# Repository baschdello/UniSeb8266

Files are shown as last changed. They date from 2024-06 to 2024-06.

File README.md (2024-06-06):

# UniSeb8266
Universal Sensorboard with ESP8266.

## Usage
### Tasmota
UniSeb8266 is designed to operate with Tasmota. Use the following template string:
```
{"NAME":"UniSeb8266","GPIO":[640,0,608,0,352,1312,0,0,0,1760,1,1728,1,0],"FLAG":0,"BASE":18}
```
### Power sources
There are different options to power the board:
| power source | SJ1 jumper position |
| --- | --- |
| HLK-PM01 230V-Module | 'module' |
| RT9400 PoE-Module | 'module' |
| 5V connector | 'connector' |
| D1-Mini USB connector  | no jumper required  |

### 3-pin connector J1
Use SJ2 to change usage of pin2:
| pin 2 utilization | SJ2 jumper position |
| --- | --- |
| 3.3V | '3V3' |
| gpio D5 | 'D5' |

Pin3 is fixed to D0.

## Examples
PM sensor mounted on diy box
<br>



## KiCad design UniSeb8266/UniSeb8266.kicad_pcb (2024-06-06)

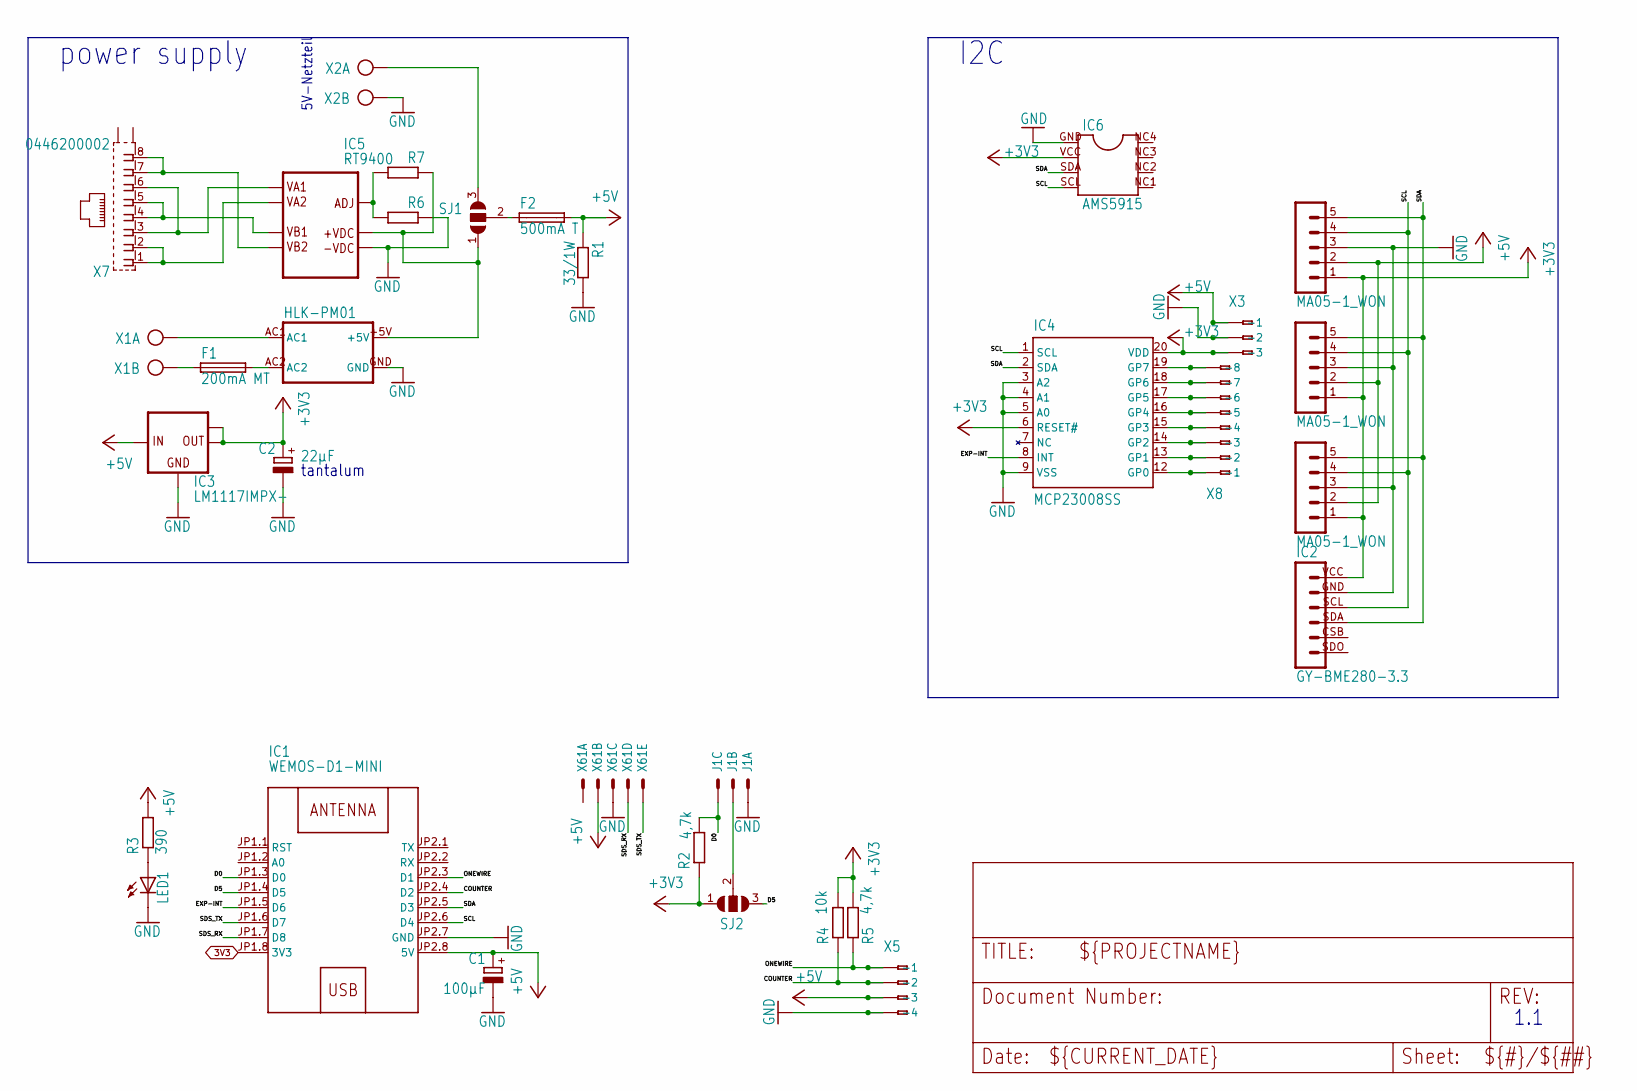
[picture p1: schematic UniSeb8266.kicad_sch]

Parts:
C1: 100µF; E2,5-6
C2: 22µF; E2,5-6
F1: 200mA MT; TR5
F2: 500mA T; TR5
I2C-1, I2C-2, I2C-3: MA05-1_WON
IC1: WEMOS-D1-MINI
IC2: GY-BME280-3.3
IC3: LM1117IMPX-; SOT223
IC4: MCP23008SS; SSOP20
IC5: RT9400
IC6: AMS5915
J1: 22-?-0327-2031; 6410-03
LED1: LED3MM
R1: 33/1W; P0613V
R2: 4,7k; R_0603_1608Metric; LCSC C23162
R3: 390; R1206
R4: 10k; R1206
R5: 4,7k; R1206
R6, R7: R-EU_R1206; R1206
SJ1, SJ2: SJ2W; SJ_2
U$2: HLK-PM01
X1, X2: AK500/2; AK500_2
X3: 233-503
X5: 233-504
X7: 0446200002
X8: 233-508
X61: JST-XH-05-PIN-LONG-PAD; JST-XH-05-PACKAGE-LONG-PAD

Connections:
3V3: IC1.JP1.8 (3V3)
+3V3: C2.+, I2C-1.1, I2C-2.1, I2C-3.1, IC2.VCC, IC3.2 (OUT), IC3.TAB (OUT1), IC4.6 (RESET#), IC4.20 (VDD), IC6.VCC (2), R2.1, R4.2, R5.2, SJ2.1, X3.A3 (-3), X3.B3 (B-3)
+5V: C1.+, F2.2, I2C-1.2, I2C-2.2, I2C-3.2, IC1.JP2.8 (5V), IC3.3 (IN), R1.1, R3.2, X3.A1 (-1), X3.B1 (B-1), X5.A3 (-3), X5.B3 (B-3), X61.2 (S)
/COUNTER: IC1.JP2.4 (D2), R4.1, X5.A2 (-2), X5.B2 (B-2)
/D0: IC1.JP1.3 (D0), J1.3 (S), R2.2
/D5: IC1.JP1.4 (D5), SJ2.3
/EXP-INT: IC1.JP1.5 (D6), IC4.8 (INT)
/ONEWIRE: IC1.JP2.3 (D1), R5.1, X5.A1 (-1), X5.B1 (B-1)
/SCL: I2C-1.4, I2C-2.4, I2C-3.4, IC1.JP2.6 (D4), IC2.SCL, IC4.1 (SCL), IC6.SCL (4)
/SDA: I2C-1.5, I2C-2.5, I2C-3.5, IC1.JP2.5 (D3), IC2.SDA, IC4.2 (SDA), IC6.SDA (3)
/SDS_RX: IC1.JP1.7 (D8), X61.4 (S)
/SDS_TX: IC1.JP1.6 (D7), X61.5 (S)
GND: C1.-, C2.-, I2C-1.3, I2C-2.3, I2C-3.3, IC1.JP2.7 (GND), IC2.GND, IC3.1 (GND), IC4.3 (A2), IC4.4 (A1), IC4.5 (A0), IC4.9 (VSS), IC5.P$5 (-VDC), IC6.GND (1), J1.1 (S), LED1.K (C), R1.2, R6.1, U$2.GND, X2.2 (KL), X3.A2 (-2), X3.B2 (B-2), X5.A4 (-4), X5.B4 (B-4), X61.3 (S)
unnamed: F1.2, U$2.AC2
unnamed: F2.1, SJ1.2
unnamed: IC4.12 (GP0), X8.A1 (-1), X8.B1 (B-1)
unnamed: IC4.13 (GP1), X8.A2 (-2), X8.B2 (B-2)
unnamed: IC4.14 (GP2), X8.A3 (-3), X8.B3 (B-3)
unnamed: IC4.15 (GP3), X8.A4 (-4), X8.B4 (B-4)
unnamed: IC4.16 (GP4), X8.A5 (-5), X8.B5 (B-5)
unnamed: IC4.17 (GP5), X8.A6 (-6), X8.B6 (B-6)
unnamed: IC4.18 (GP6), X8.A7 (-7), X8.B7 (B-7)
unnamed: IC4.19 (GP7), X8.A8 (-8), X8.B8 (B-8)
unnamed: IC5.P$6 (+VDC), R7.1, SJ1.1, U$2.+5V
unnamed: IC5.P$7 (ADJ), R6.2, R7.2
unnamed: IC5.P$1 (VA1), X7.3, X7.6
unnamed: IC5.P$2 (VA2), X7.1, X7.2
unnamed: IC5.P$3 (VB1), X7.4, X7.5
unnamed: IC5.P$4 (VB2), X7.7, X7.8
unnamed: J1.2 (S), SJ2.2
unnamed: LED1.A, R3.1
unnamed: U$2.AC1, X1.1 (KL)
unnamed: F1.1, X1.2 (KL)
unnamed: SJ1.3, X2.1 (KL)

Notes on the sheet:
I2C
5V-Netzteil
tantalum
power supply
1.1

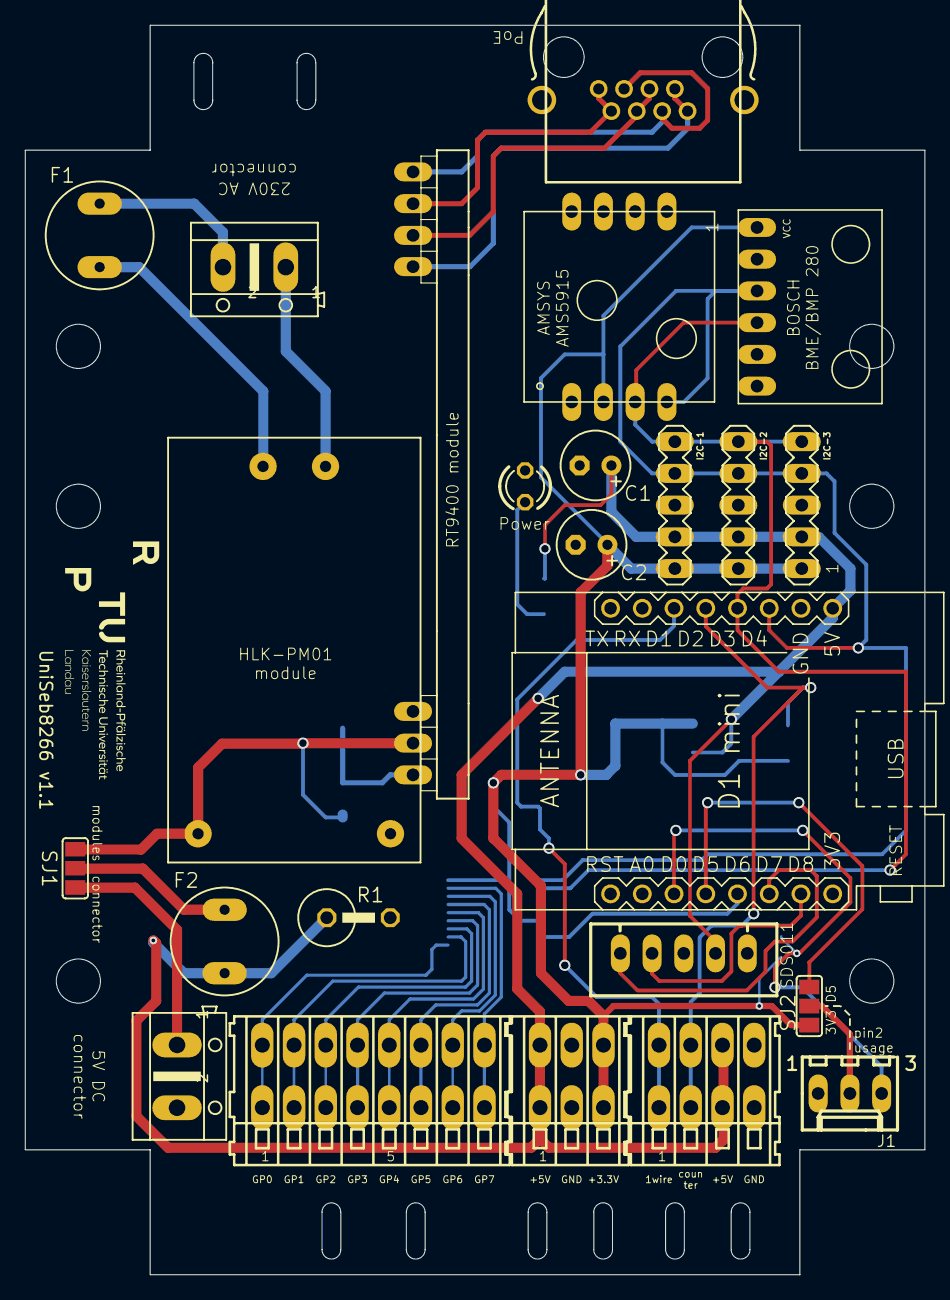
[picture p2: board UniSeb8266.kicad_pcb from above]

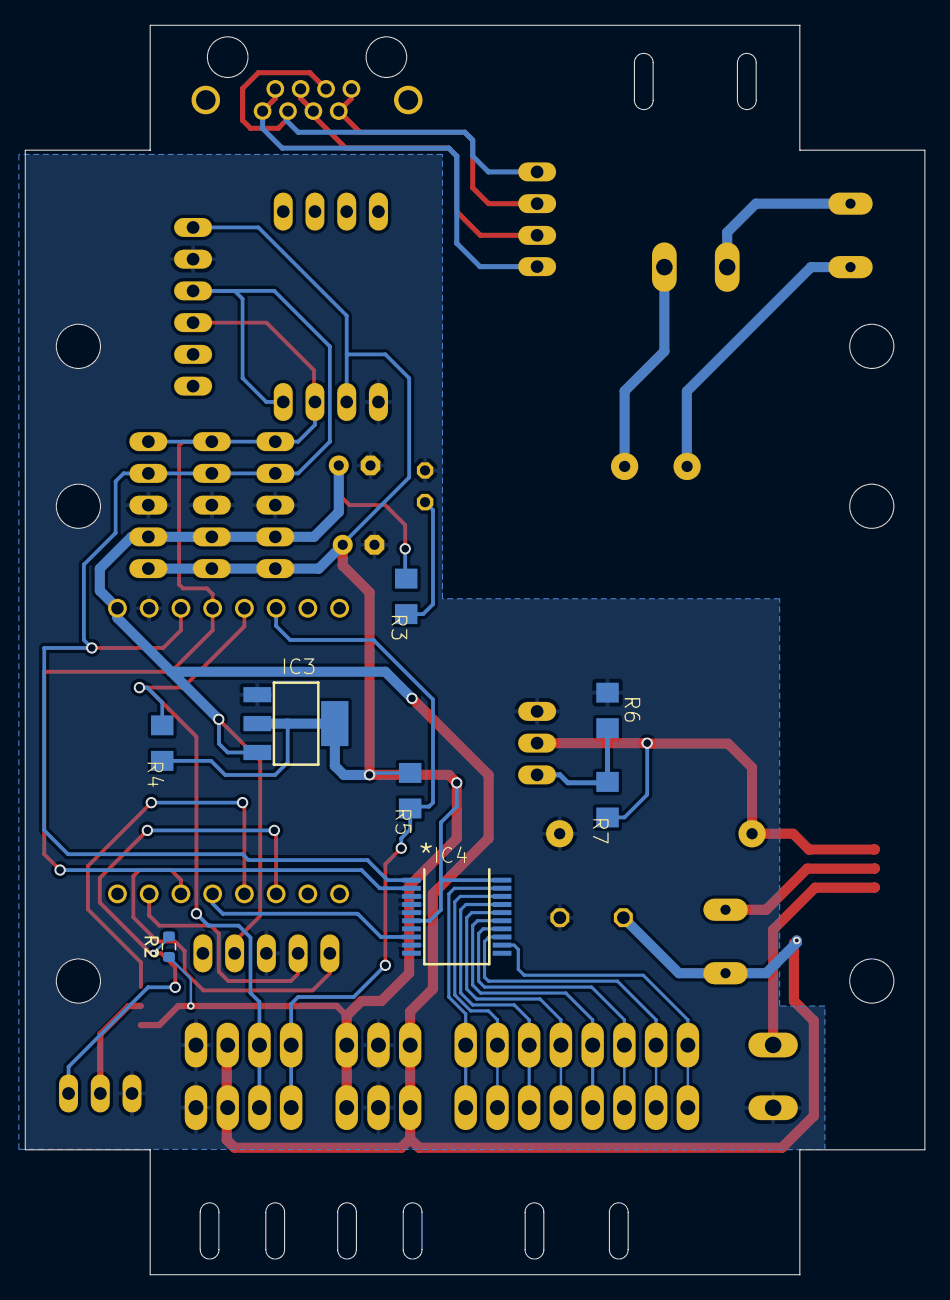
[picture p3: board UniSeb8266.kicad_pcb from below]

Board: 2 copper layers, 72.0 x 100.0 mm, 32 parts (8 on the bottom side), 33 nets.

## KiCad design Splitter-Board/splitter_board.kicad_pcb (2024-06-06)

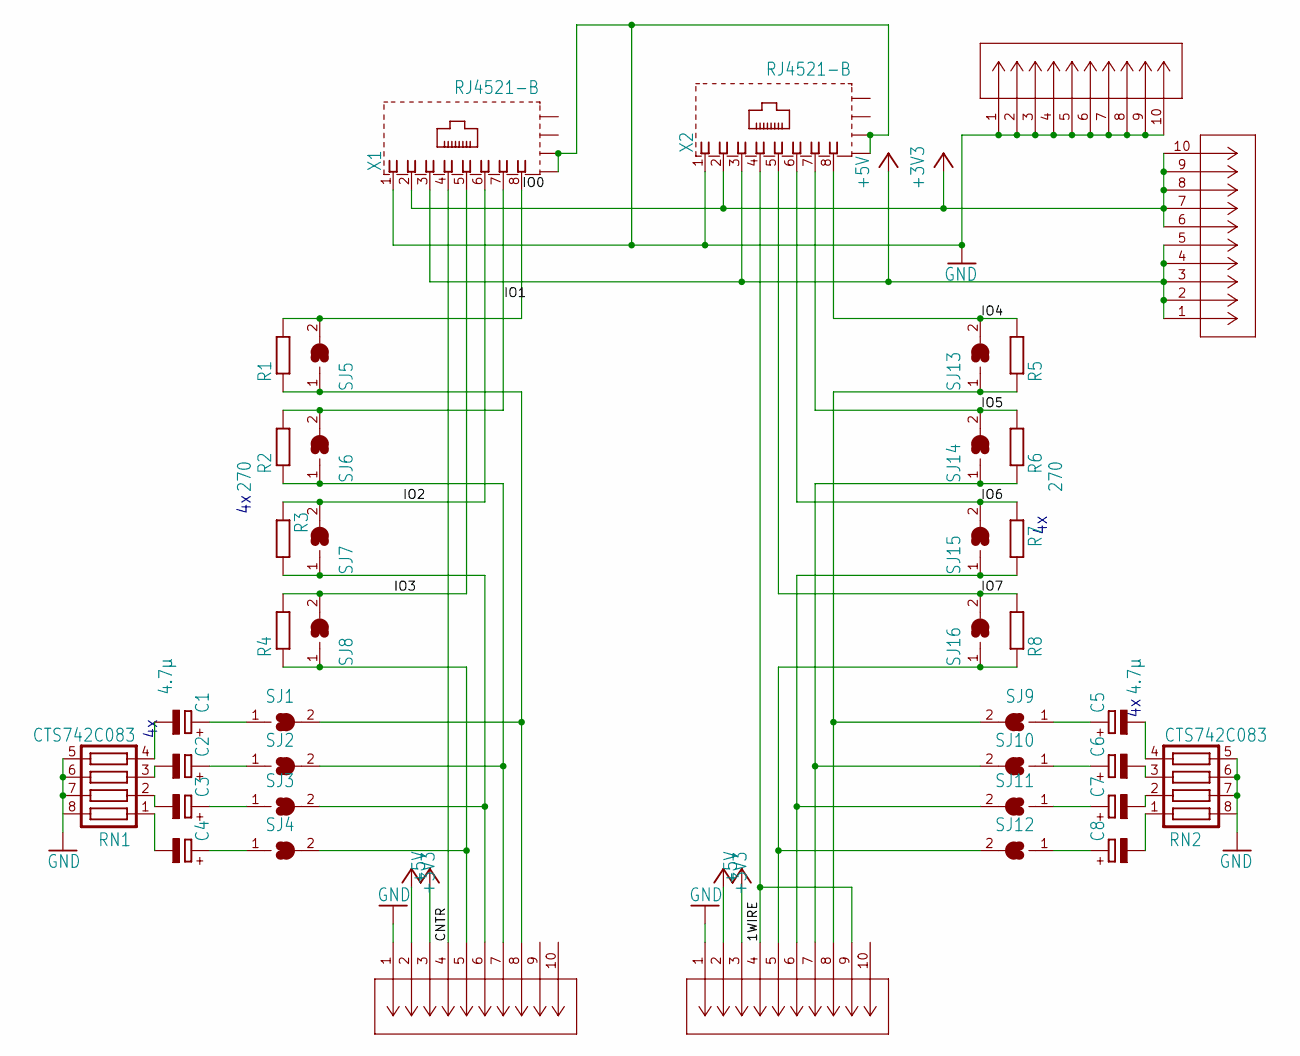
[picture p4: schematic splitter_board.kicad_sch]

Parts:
C1, C2, C3, C4, C5, C6, C7, C8: 4.7µ; A_3216-18R; JLC C110309
J1, J2, J3, J4: 250-410; CONN_250-410_WAG
R1, R2, R3, R4, R5, R6, R7, R8: 270; R0805
RN1, RN2: CTS742C083
SJ1, SJ2, SJ3, SJ4, SJ5, SJ6, SJ7, SJ8, SJ9, SJ10, SJ11, SJ12, SJ13, SJ14, SJ15, SJ16: SJ
X1, X2: RJ4521-B; RJ45-SHIELD1

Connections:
1WIRE: J2.4, J2.9, X2.4
+3V3: J1.2, J2.2, J4.6, J4.7, J4.8, J4.9, J4.10, X1.2, X2.2
+5V: J1.3, J2.3, J4.1, J4.2, J4.3, J4.4, J4.5, X1.3, X2.3
CNTR: J1.4, X1.4
GND: J1.1, J2.1, J3.1, J3.2, J3.3, J3.4, J3.5, J3.6, J3.7, J3.8, J3.9, J3.10, RN1.5, RN1.6, RN1.7, RN1.8, RN2.5, RN2.6, RN2.7, RN2.8, X1.1, X1.S1 (S@1), X1.S2 (S@2), X2.1, X2.S1 (S@1), X2.S2 (S@2)
IO0: R1.2, SJ5.2, X1.8
IO1: R2.2, SJ6.2, X1.7
IO2: R3.2, SJ7.2, X1.6
IO3: R4.2, SJ8.2, X1.5
IO4: R5.2, SJ13.2, X2.8
IO5: R6.2, SJ14.2, X2.7
IO6: R7.2, SJ15.2, X2.6
IO7: R8.2, SJ16.2, X2.5
unnamed: C8.-, RN2.1
unnamed: C7.-, RN2.2
unnamed: C6.-, RN2.3
unnamed: C5.-, RN2.4
unnamed: C4.-, RN1.1
unnamed: C3.-, RN1.2
unnamed: C2.-, RN1.3
unnamed: C1.-, RN1.4
unnamed: C5.+, SJ9.1
unnamed: C6.+, SJ10.1
unnamed: C7.+, SJ11.1
unnamed: C8.+, SJ12.1
unnamed: J2.8, R5.1, SJ9.2, SJ13.1
unnamed: J2.7, R6.1, SJ10.2, SJ14.1
unnamed: J2.6, R7.1, SJ11.2, SJ15.1
unnamed: J2.5, R8.1, SJ12.2, SJ16.1
unnamed: C1.+, SJ1.1
unnamed: C2.+, SJ2.1
unnamed: C3.+, SJ3.1
unnamed: C4.+, SJ4.1
unnamed: J1.7, R2.1, SJ2.2, SJ6.1
unnamed: J1.8, R1.1, SJ1.2, SJ5.1
unnamed: J1.6, R3.1, SJ3.2, SJ7.1
unnamed: J1.5, R4.1, SJ4.2, SJ8.1

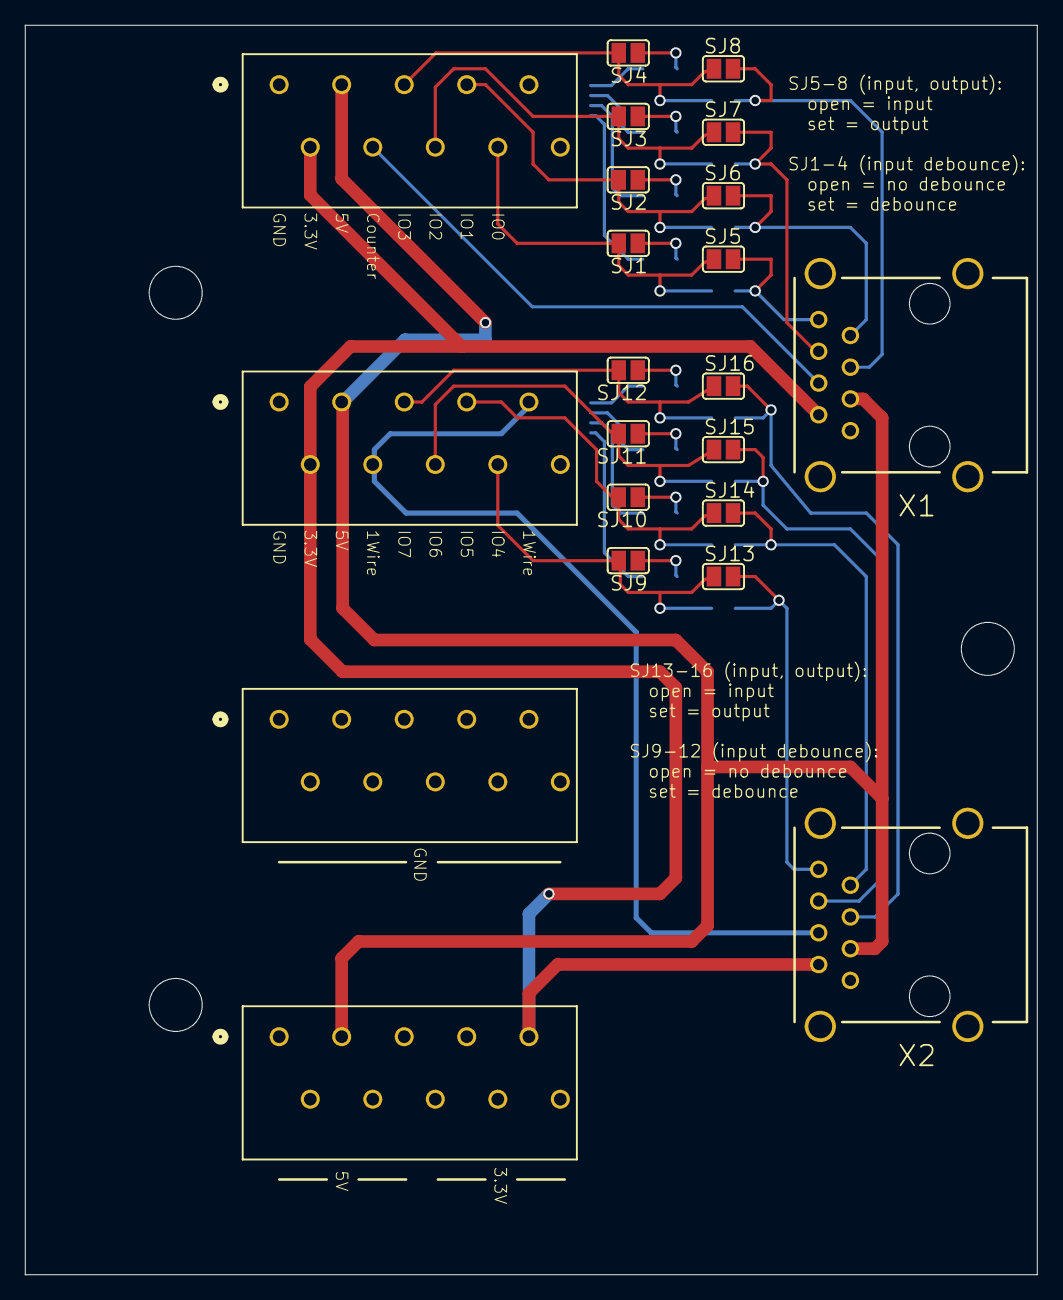
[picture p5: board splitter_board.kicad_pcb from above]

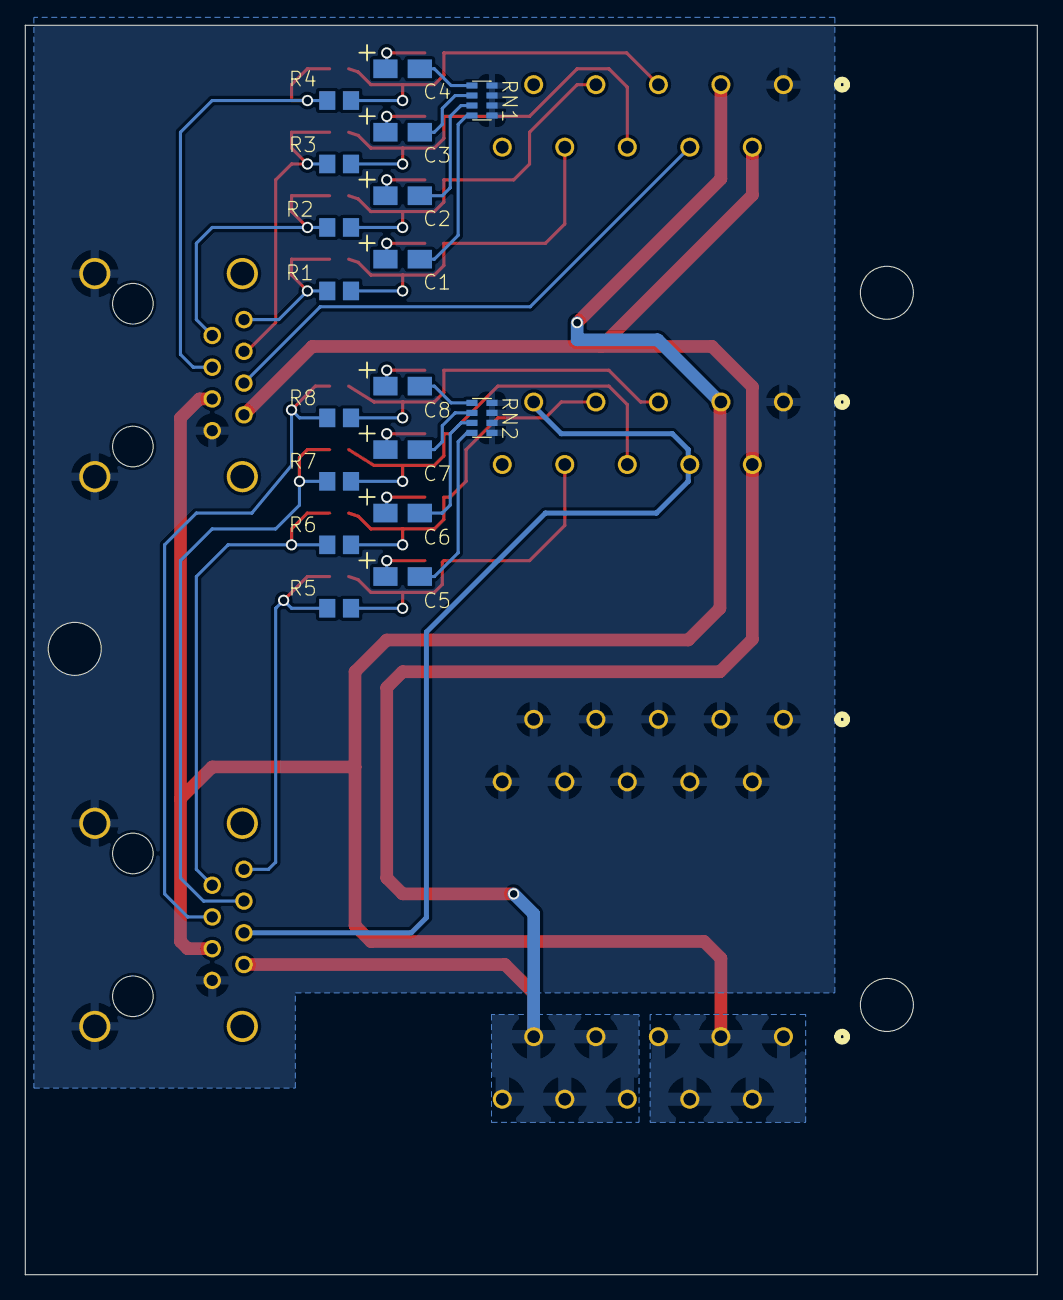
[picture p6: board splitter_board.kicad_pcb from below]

Board: 2 copper layers, 81.0 x 100.0 mm, 40 parts (18 on the bottom side), 37 nets.

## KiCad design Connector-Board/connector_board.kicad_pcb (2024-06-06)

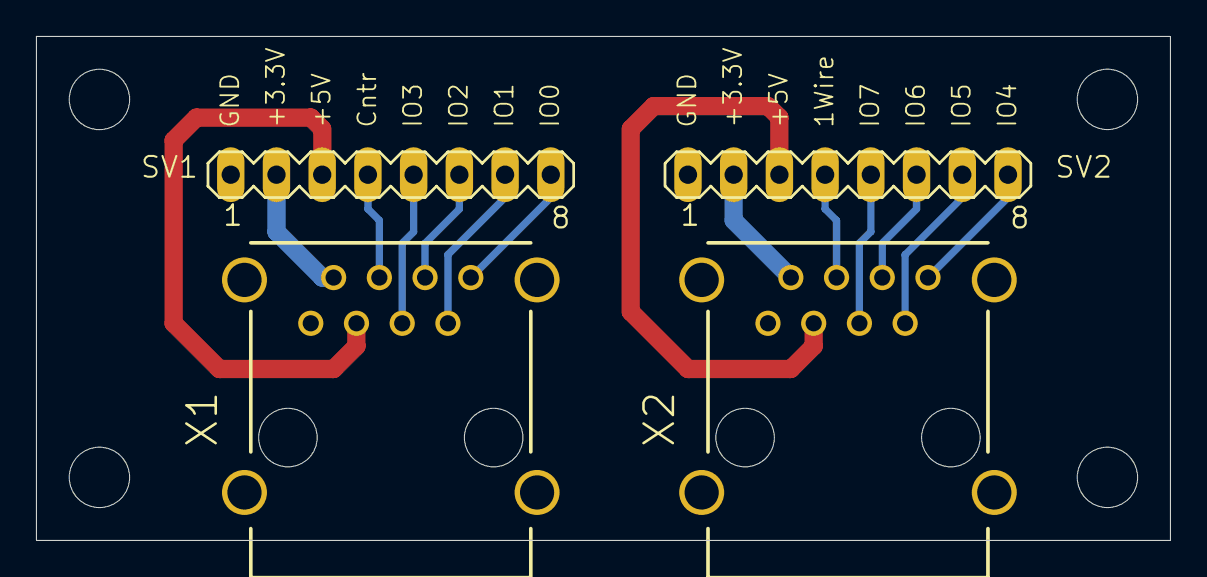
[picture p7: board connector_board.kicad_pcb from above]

Board: 2 copper layers, 63.0 x 28.0 mm, 4 parts (0 on the bottom side), 15 nets.

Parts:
SV1, SV2: MA08-1
X1, X2: RJ45-6L21-B; RJ45-SHIELD1

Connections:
GND: SV1.1, SV2.1, X1.1, X1.S1, X1.S2, X1.S3, X1.S4, X2.1, X2.S1, X2.S2, X2.S3, X2.S4
unnamed: SV1.3, X1.3
unnamed: SV1.4, X1.4
unnamed: SV1.5, X1.5
unnamed: SV1.6, X1.6
unnamed: SV1.7, X1.7
unnamed: SV1.8, X1.8
unnamed: SV2.3, X2.3
unnamed: SV2.4, X2.4
unnamed: SV2.5, X2.5
unnamed: SV2.6, X2.6
unnamed: SV2.7, X2.7
unnamed: SV2.8, X2.8
unnamed: SV1.2, X1.2
unnamed: SV2.2, X2.2

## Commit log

2020-01-28 Changed the fixed voltage regulator to AMS1117/LM1117 and the output capacitor.
    [BOM.xlsx, UniSeb8266.brd, UniSeb8266.sch]
2020-02-09 Changed placement of IC3 to bottom layer.
    [UniSeb8266.brd]
2021-06-11 rear/front connector board
    [connector_board.brd, connector_board.sch]
2022-07-11 added PCBs for extern IO-connections
    [BOM_UniSeb8266.xlsx, connector_board.brd, connector_board.sch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]
2024-06-06 migration to KiCad
    [UniSeb8266.kicad_pcb, UniSeb8266.kicad_sch, connector_board.kicad_pcb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]
2024-06-06 changed name of SJ2 -> SJ1
    [UniSeb8266.kicad_pcb, UniSeb8266.kicad_sch]
2024-06-06 added SJ2 to change pin-2 usage of "Molex KK 254" connector (3.3V or D5)
    [UniSeb8266.kicad_pcb, UniSeb8266.kicad_sch]
2024-06-06 added R2 pullup for pin3 of J1
    [UniSeb8266.kicad_pcb, UniSeb8266.kicad_sch]
